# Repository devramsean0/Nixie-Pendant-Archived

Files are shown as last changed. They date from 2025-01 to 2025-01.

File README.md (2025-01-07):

Github Nixie Pendant Logo(1)

A DIY, wearable pendant made from an IN-16 and quite a few boards

> [!CAUTION]
> This project contains high voltage electronics, It could concevably kill you and it will hurt.
> Don't leave children unnatended and exercise caution

## Key Voltages
LV: 3.3v, HV: 170v

## Planned electrical stackup
This is in order of closest to tube
1. Socket PCB
2. Control PCB
3. High Voltage Generation PCB
4. BMS board
5. Programming/Charging board
6. Battery

## Folder Layout
- `bms/` - Board files for the BMS (Battery Management System), handles lipo charging and safe discharge, usb & battery cutover and power regulation to the LV rail
- `socket/` - My bootleg IN-16 socket, very simple. just pads and holes. but like, this should hold the tube in (probably)
- `PendantLib.pretty/` - Shared part footprints

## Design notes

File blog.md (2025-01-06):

> [!CAUTION]
> This project contains high voltage electronics, It could concevably kill you and it will hurt.
> Don't leave children unnatended and exercise caution

# Project overview
So, I wanted to put a working nixie tube around my neck.

# Initial plans
I wanted to use a IN-16 tube, as I didn't want it to get dwarfed by the electronics, and wanted it to all fit underneath it.
I've also ended up with quite a few different PCB's in the stack because of the incredibly small surface area.

## Key voltages and voltage information
The low voltage rails will predominantly be 3.3, this voltage powers the control circuitry and is passed to the high voltage generation circuitry. It is designed this way, to minimise the additional components, caused by having to further regulate it down for the controller. The High voltage is supposed to be 170v

Other voltages that are present are:
- 5v on the BMS
- 3.7v on the BMS

## Planned Electrical Stackup
In order of closest to the tube
1. Socket PCB
2. Control PCB
3. High Voltage Gen PCB
4. BMS/Low Voltage PCB
5. Programming/Charging PCB
6. Lipo Battery

# Designing the PCBs
## BMS PCB
### The requirements
1. Handle battery charging
2. Handle safe discharge
3. Handle voltage switchover
4. Handle power regulation to 3.3v from either 5v or 3.7v
5. Contain connection points for a power switch

### Rev 1
This revision was my first proper attempt. While I managed to get it within the limited space and only on 1 side (reducing fab costs). I forgot power regulation, switch solder points and a mounting hole in the center
{{Rev 1 Photo - Copy in BSX Mods #pcb-design}}
### Rev 2
Rev 2, This was attempt 2. I remembered the voltage regulator, however I forgot the mounting hole and the switch points. I also ended up going onto the back of the PCB
{{Rev 2 Photos - Copy in Alex's DMs}}
### Rev 3
Attempt 3... Attempt 3! This revision finally adds a 1.5mm mounting hole and the points for the switch (although this is getting tight!)

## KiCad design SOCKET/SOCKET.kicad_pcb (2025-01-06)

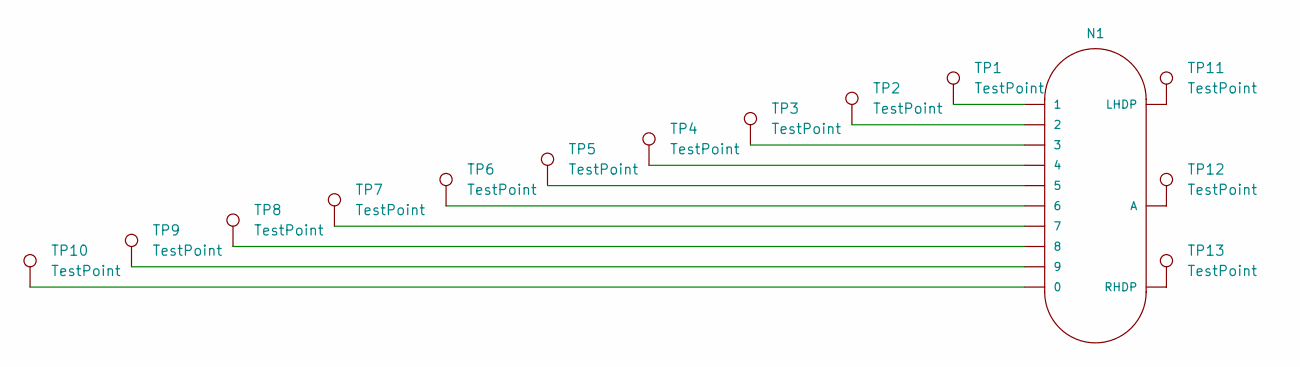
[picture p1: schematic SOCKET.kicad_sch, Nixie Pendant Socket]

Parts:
N1: IN-16; nixies-us-IN-16
TP1, TP2, TP3, TP4, TP5, TP6, TP7, TP8, TP9, TP10, TP11, TP12, TP13: TestPoint; TestPoint_Pad_1.0x1.0mm

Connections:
unnamed: N1.0, TP10.1
unnamed: N1.1, TP1.1
unnamed: N1.2, TP2.1
unnamed: N1.3, TP3.1
unnamed: N1.4, TP4.1
unnamed: N1.5, TP5.1
unnamed: N1.6, TP6.1
unnamed: N1.7, TP7.1
unnamed: N1.8, TP8.1
unnamed: N1.9, TP9.1
unnamed: N1.A, TP12.1
unnamed: N1.LHDP, TP11.1
unnamed: N1.RHDP, TP13.1

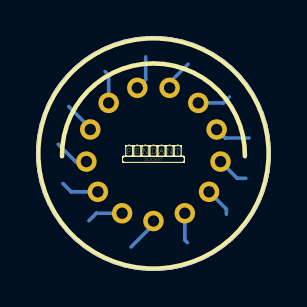
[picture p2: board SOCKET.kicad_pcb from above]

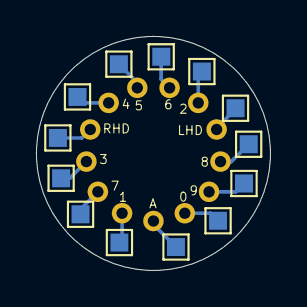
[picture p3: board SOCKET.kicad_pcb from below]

Board: 2 copper layers, 13.0 x 13.0 mm, 14 parts (13 on the bottom side), 13 nets.

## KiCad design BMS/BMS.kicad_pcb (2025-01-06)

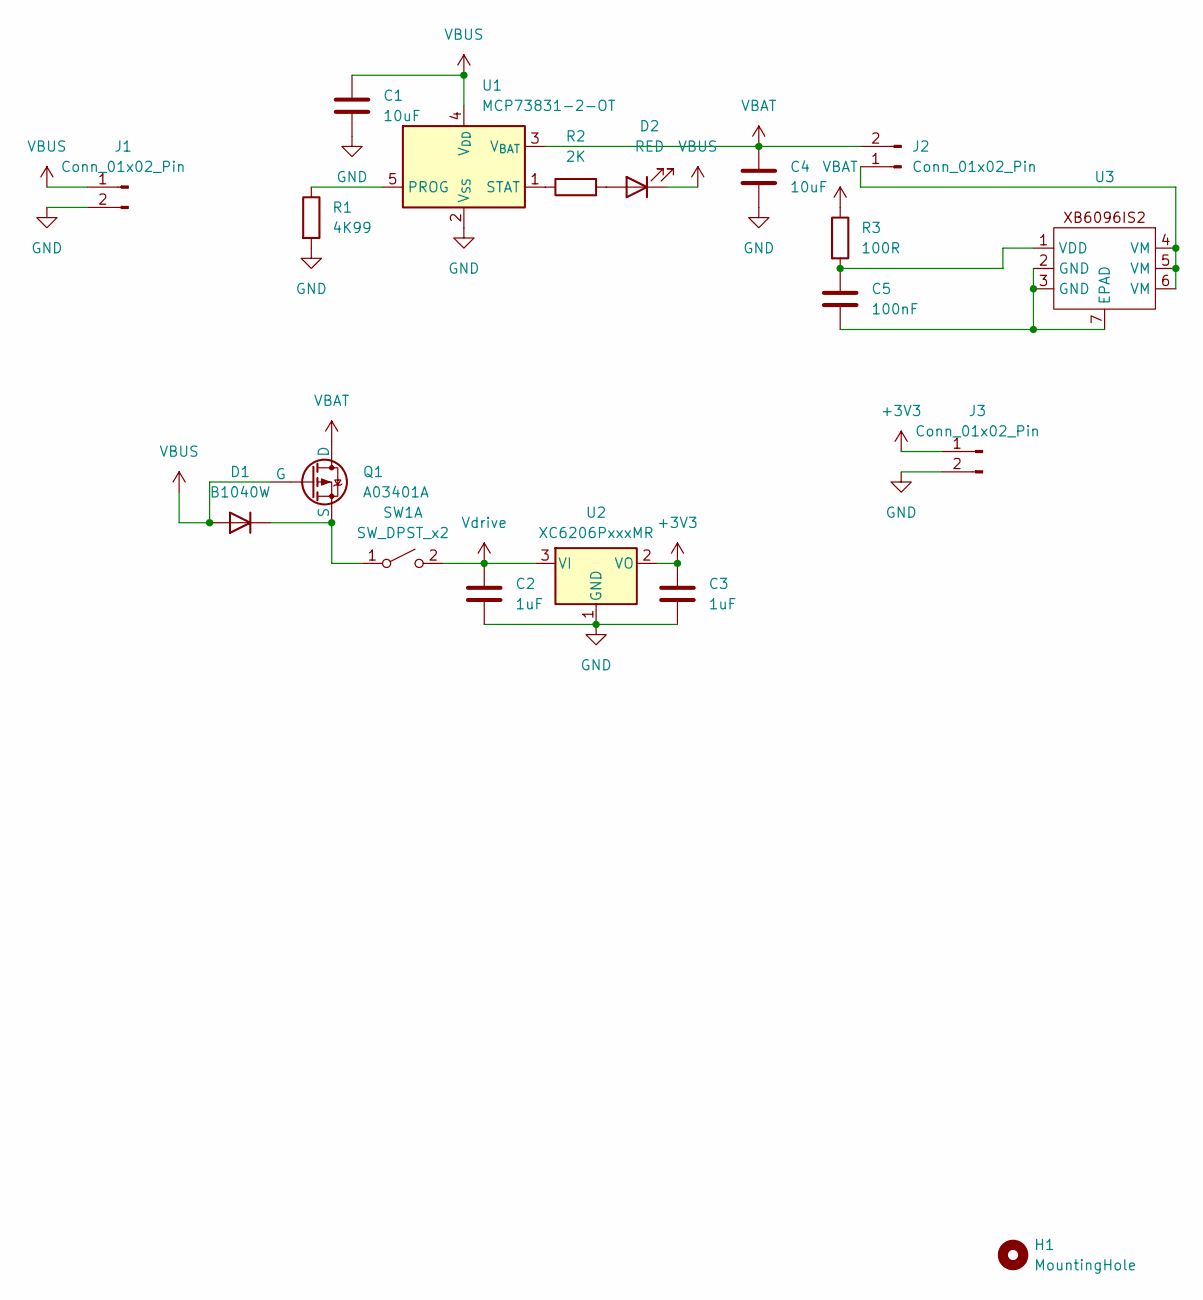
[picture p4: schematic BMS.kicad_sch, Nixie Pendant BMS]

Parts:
C1, C4: 10uF; C_0402_1005Metric
C2, C3: 1uF; C_0402_1005Metric
C5: 100nF; C_0402_1005Metric
D1: B1040W; D_SOD-123
D2: RED; LED_0603_1608Metric
H1: MountingHole; MountingHole_1.5mm
J1, J2, J3: Conn_01x02_Pin; PinHeader_2x01_P1.00mm_Vertical
Q1: A03401A; TSOT-23
R1: 4K99; R_0402_1005Metric
R2: 2K; R_0402_1005Metric
R3: 100R; R_0402_1005Metric
SW1: SW_DPST_x2; PinHeader_2x01_P1.00mm_Vertical
U1: MCP73831-2-OT; SOT-23-5
U2: XC6206PxxxMR; SOT-23-3
U3: DFN-6-1EP_2x2mm_P0.5mm_EP0.6x1.37mm

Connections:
+3V3: C3.1, J3.1, U2.2 (VO)
GND: C1.2, C2.2, C3.2, C4.2, J1.2, J3.2, R1.2, U1.2 (V_{SS}), U2.1 (GND)
unnamed: D1.1 (K), Q1.3 (S), SW1.1 (A)
unnamed: D2.2 (A), R2.2
unnamed: J2.1, U3.4 (VM), U3.5 (VM), U3.6 (VM)
unnamed: R1.1, U1.5 (PROG)
unnamed: R2.1, U1.1 (STAT)
unnamed: C5.2, U3.2 (GND), U3.3 (GND), U3.7 (EPAD)
unnamed: C5.1, R3.2, U3.1 (VDD)
VBAT: C4.1, J2.2, Q1.1 (D), R3.1, U1.3 (V_{BAT})
VBUS: C1.1, D1.2 (A), D2.1 (K), J1.1, Q1.2 (G), U1.4 (V_{DD})
Vdrive: C2.1, SW1.2 (B), U2.3 (VI)

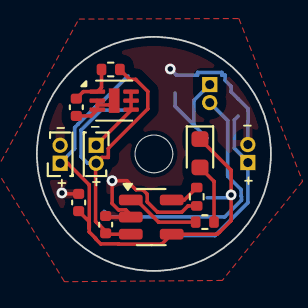
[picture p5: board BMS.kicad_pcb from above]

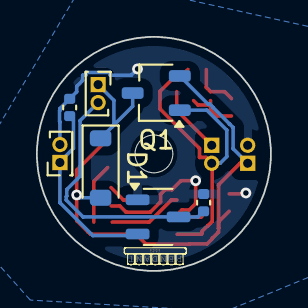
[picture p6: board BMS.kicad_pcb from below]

Board: 2 copper layers, 13.0 x 13.0 mm, 19 parts (7 on the bottom side), 12 nets.

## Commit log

2024-12-21 BMS Board
    [BMS.kicad_pcb, BMS.kicad_sch]
2025-01-05 BMS Rev 2
    [BMS.kicad_pcb, BMS.kicad_sch]
2025-01-06 BMS rev 3, Shared lib, WIP blog, A readme
2025-01-06 Some BMS changes?, Socket PCB
    [BMS.kicad_pcb, BMS.kicad_sch, SOCKET.kicad_pcb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]
